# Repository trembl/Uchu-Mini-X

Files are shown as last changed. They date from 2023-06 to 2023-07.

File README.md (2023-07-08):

# 宇宙 Uchi Mini X4000

The 宇宙 (うちゅう, uchū) "Kosmos" Mini X4000 is a re-imagination of a popular Kosmos Electronics construction kits ("[Experimentierkasten](https://de.wikipedia.org/wiki/Experimentierkasten)") from th 1980ies.

I still have the instruction books for the X1000-X2000 and X3000-X4000 sets, but I only every got the X2000 and the X2500 Extenstion Set, I could make all the experiments up to the X3000, but not the X4000.

With this re-making of the complete set, I'll finally be able to make **all** the experiments!

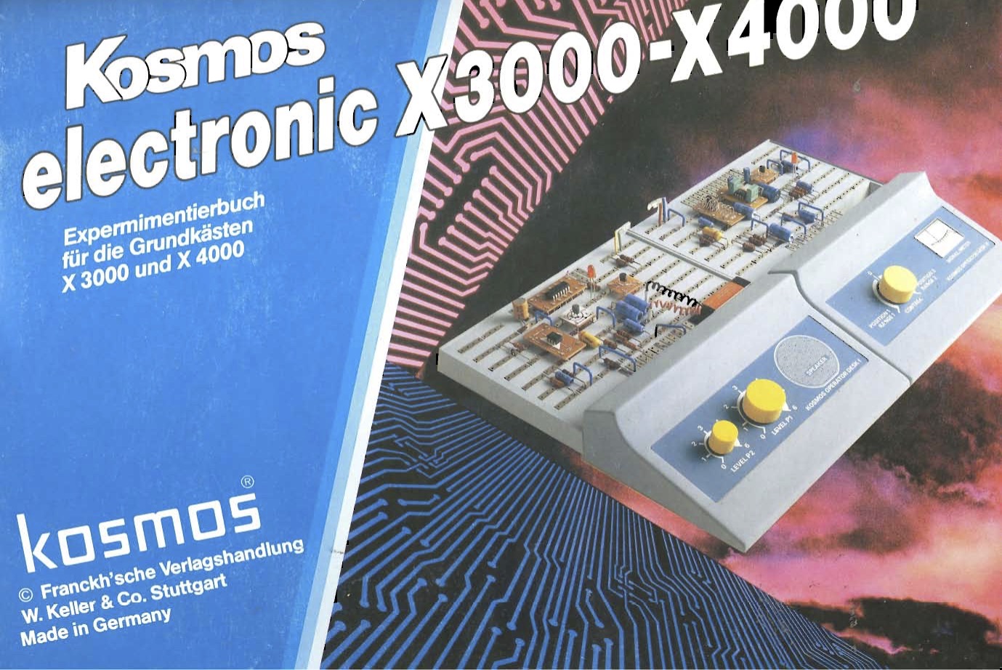
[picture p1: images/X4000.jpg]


The Kosmos X-Series was followed by the XN-Series, which introduces a different chassis and some addtional parts (Variable Capacitor, 555 Timer)

## Todo
- [X] Identify the parts and create a complete [BoM (Bill of Materials)](BoM.md)
- [X] Find where to source the parts - and how much they cost
- [X] PCB Design the Main Board
- [X] 3D Model the Main Board Carrier
- [ ] PCB Design the small carrier boards for IC, AMPs, etc
- [ ] Mill the Boards
- [ ] 3D Model the Console ("Schaltpult") & Enclosures
- [ ] 3D Print the Console & Enclosures

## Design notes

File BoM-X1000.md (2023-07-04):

# Bill of Materials X1000 (Box I)

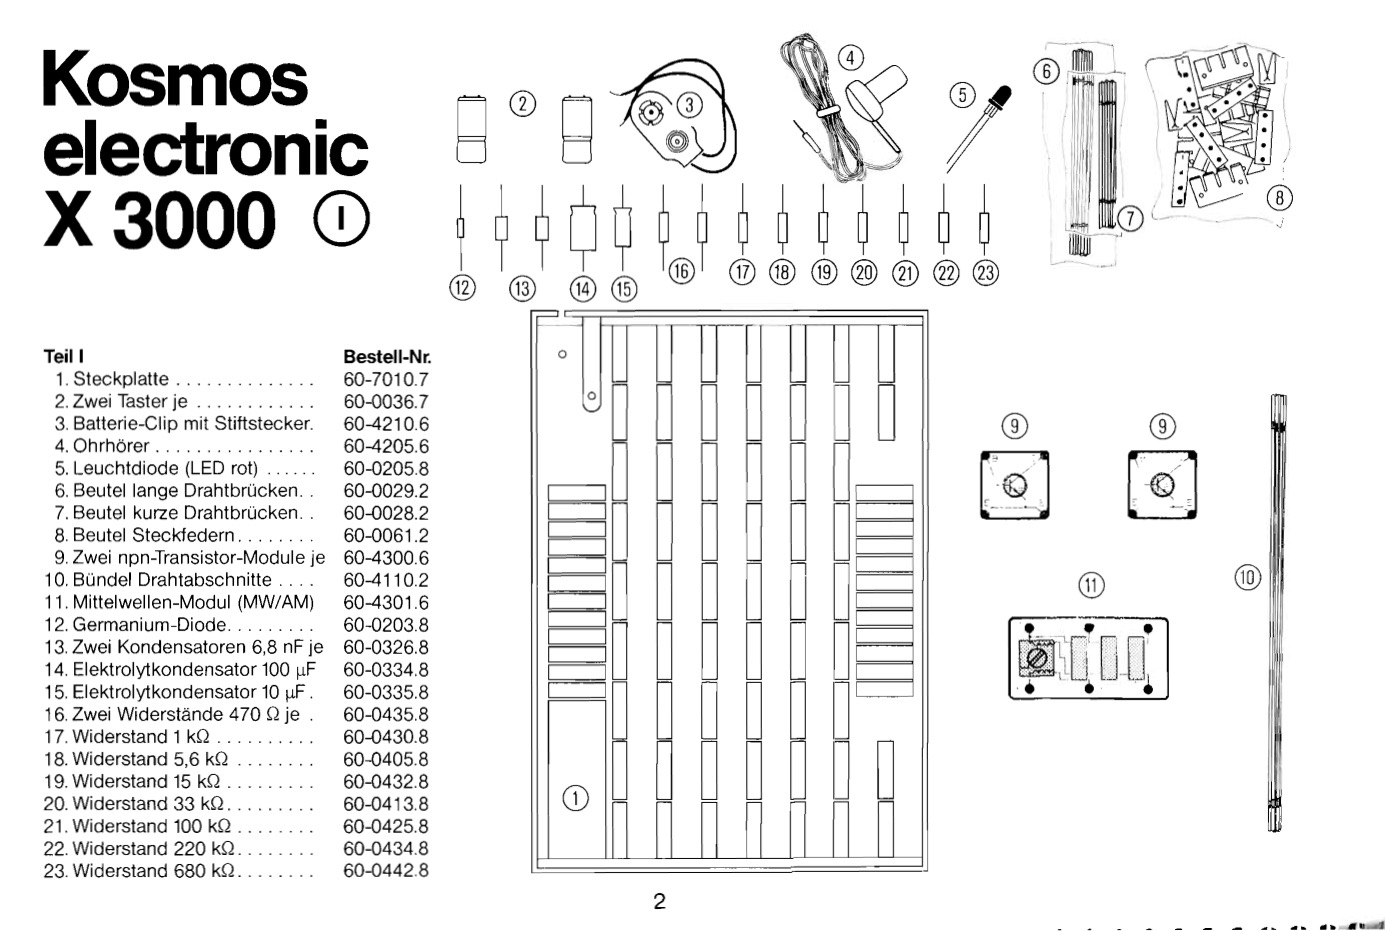
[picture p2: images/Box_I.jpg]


| Nr  | Description | Alternative | Package | Unit Price |  Bulk Price |
| --- | --- | --- | --- | --- | --- |
| 1.  | Main Board | TODO: 3D Design | | | |
| 2.  | Switch (x2) | [↓](#switch-module) | | | |
| 3.  | ✅ 9V Battery Clip | [9V Battery Clip](https://akizukidenshi.com/catalog/g/gP-00452/) 🅰️[^1] 1F06 | | ¥20 | |
| 4.  | Earpiece, 8Ω | TODO: Find with Crystal Radio Set | | | |
| 5.  | ✅ Red LED, 5mm | [Red LED, 5mm](https://akizukidenshi.com/catalog/g/gI-06245/) 🅰️[^1] 1F25/2 | Through-Hole | ¥12 | ¥120 for 10 |
| 6.  | ✅ Long Wires | [Wire Set](https://akizukidenshi.com/catalog/g/gP-05160/)| | ¥400 | |
| 7.  | Short Wires | See 6. | | | |
| 8.  | ✅ Pin Headers 1x4, 2.54mm, Black | [Pin Header 1x4](https://akizukidenshi.com/catalog/g/gC-10099/) 🅰️[^1] 1F12/下, C-10099| Through-Hole | ¥20 |  |
| 8.A  | Pin Headers 1x40, 2.54mm, Red, Yellow, Gray, Green | ✅ [Pin Header 1x40](https://akizukidenshi.com/catalog/g/gC-10299/), 🅰️[^1]1F12/下, C-10299 | Through-Hole | ¥100 | ¥10 for 1x4 |
| 8.B  | Pin Headers 1x40, 2.54mm, Black | ✅ [Pin Header 1x40](https://akizukidenshi.com/catalog/g/gC-10073/) 🅰️[^1] 1F12/下, C-10073| Through-Hole | ¥80 | ¥8 for 1x4 |
| 9.  | NPN Transitor Module (x2) | [↓](#npn-transistor-module) | | | |
| 10. | Very Long Wires | See 6. | | | |
| 11. | [MW/AM Module](https://www.rigert.com/ee-wiki/index.php?title=KOSMOS_Mittelwellen-Modul) | [↓](#mw-am-module) | | | |
| 12. | Diode (Germanium), AA112, AA118, 1N60, AA113 |⚠️ [1N60](https://akizukidenshi.com/catalog/g/gI-05507/) 🅰️[^1] 1F21/2, I-05507 | Through-Hole | ¥25 | 10 for ¥250 |
| 13.A | Capacitor 6.8nF (x2) | ⚠️ [6800pF50V X7R 5mm](https://akizukidenshi.com/catalog/g/gP-08137/) 🅰️[^1] 1F22/2, P-08137 | Through-Hole, Radial (x10) | ¥10 | ¥100 |
| 13.B | Capacitor 6.8nF (x2) | ⚠️ [XICON 23PS268 Styrofoam Capacitor 50V6800pF](https://www.sengoku.co.jp/mod/sgk_cart/detail.php?code=EEHD-4ET7#) 💎[^3] | Through-Hole, Axial | ¥111 | |
| 14.A | Capacitor 100µF, bi-polar, axial | ⚠️ [107BPA016M](https://www.digikey.jp/en/products/detail/cornell-dubilier-illinois-capacitor/107BPA016M/5410731) 🔑[^2] | Through-Hole, Axial | ¥198 | |
| 14.B | Capacitor 100µF, bi-polar | ⚠️ [100µF16V](https://akizukidenshi.com/catalog/g/gP-10271/) 🅰️[^1] 1F09/下, P-10271 | Through-Hole | ¥20 | |
| 14.C | Capacitor 100µF, bi-polar, axial | ⚠️ [100µF50V, UNICON GST1H101M](https://www.sengoku.co.jp/mod/sgk_cart/detail.php?code=EEHD-0GMP) 💎[^3] | Through-Hole | ¥105 | |
| 15.A | Capacitor 10µF, bi-polar, axial | ⚠️ [106BPA050M](https://www.digikey.jp/en/products/detail/cornell-dubilier-illinois-capacitor/106BPA050M/5410614) 🔑[^2] | Through-Hole, Axial | ¥150 | |
| 15.B | Capacitor 10µF, bi-polar | ⚠️ [10µF25V](https://akizukidenshi.com/catalog/g/gP-17877/) 🅰️[^1]1F09/下, P-17877 | Through-Hole | ¥20 | |
| 15.C | Capacitor 10µF, bi-polar, axial | ⚠️ [10µF50V, UNICON GST1H100M](https://www.sengoku.co.jp/mod/sgk_cart/detail.php?code=EEHD-0GMK) 💎[^3] | Through-Hole | ¥105 | |
| 16. | Resistor 470Ω (x2) | ✅ [1/2W 470Ω](https://akizukidenshi.com/catalog/g/gR-07814/) | Through-Hole, Axial (x100) | ¥1 | ¥100 |
| 17. | Resistor 1㏀ | ✅ [1/2W 1㏀](https://akizukidenshi.com/catalog/g/gR-07820/) | Through-Hole, Axial (x100) | ¥1.5 | ¥100 |
| 18. | Resistor 5.6㏀ | ✅ [1/4W 5.6㏀](https://akizukidenshi.com/catalog/g/gR-25562/) | Through-Hole, Axial (x100) | ¥1 | ¥100 |
| 19. | Resistor 15㏀ | ✅ [1/2W 15㏀](https://akizukidenshi.com/catalog/g/gR-07840/) | Through-Hole, Axial (x100) | ¥1 | ¥100 |
| 20. | Resistor 33㏀ | ✅ [1/2W 33㏀](https://akizukidenshi.com/catalog/g/gR-07812/) | Through-Hole, Axial (x100) | ¥1 | ¥100 |
| 21. | Resistor 100㏀ | ✅ [1/2W 100㏀](https://akizukidenshi.com/catalog/g/gR-07853/) | Through-Hole, Axial (x100) | ¥1 | ¥100 |
| 22. | Resistor 220㏀ | ✅ [1/2W 220㏀](https://akizukidenshi.com/catalog/g/gR-07858/) | Through-Hole, Axial (x100) | ¥1 | ¥100 |
| 23. | Resistor 680㏀ | ✅ [1/4W 680㏀](https://akizukidenshi.com/catalog/g/gR-25684/) | Through-Hole, Axial (x100) | ¥1 | ¥100 |

### General
| Nr  | Description | Alternative | Package | Unit Price |  Bulk Price |
| --- | --- | --- | --- | --- | --- |
| X  | Pin Headers 1x40 (x10)  | ⚠️ [Color Pin Headers](https://akizukidenshi.com/catalog/g/gC-06641/) 🅰️[^1]1F12/下, C-06641 | | ¥550 | ¥1.375 for 1 |
| X  | L-Pin Sockets 1x6 | ✅ [L-Pin Sockets](https://akizukidenshi.com/catalog/g/gC-03795/) 🅰️[^1]1F12/下, C-03795 | | ¥20 | |

### Switch Module
| Nr  | Description | Alternative | Package | Unit Price |  Bulk Price |
| --- | --- | --- | --- | --- | --- |
| 2.1  | SMD Switch (x2) | SMD Switch | | | |
| 2.2  | Module PCB | TODO: Design & Mill PCB Design | | | |

### NPN Transistor Module
| Nr  | Description | Alternative | Package | Unit Price |  Bulk Price |
| --- | --- | --- | --- | --- | --- |
| 9.1A  | NPN Transitor Module, BC583C, BC238C, BC548C BJT 100mA 30V NPN | ⚠️ [BC848BLT1G](https://www.digikey.jp/en/products/detail/onsemi/BC848BLT1G/918348) 🔑[^2] | SOT23-3 | ¥21 | ¥42 |
| 9.1B  | NPN Transitor Module 100mA 60V | ⚠️ [2PD601AR 50V100mA](https://akizukidenshi.com/catalog/g/gI-02231/) 🅰️[^1]NA, Online Only | SOT23 | 0.625¥ | 80 for ¥50 |
| 9.1C  | NPN Transitor Module 100mA 60V | ⚠️ [2SC3324-GR 120V100mA](https://akizukidenshi.com/catalog/g/gI-09371/) 🅰️[^1]1F23/4, I-09371 | SC-59 | 25¥ | 5 for ¥150 |
| 9.2  | Module PCB | TODO: Design & Mill PCB Design | | | |

### MW/AM Module
| Nr  | Description | Alternative | Package | Unit Price |  Bulk Price |
| --- | --- | --- | --- | --- | --- |
| 11.1 | Toko RCL XYRS 18194 N5 86152 | ⚠️ [Murata](https://www.digikey.jp/en/products/detail/murata-electronics/A1313B-0029GGH-P3/13244738) | 6-SMD | ¥226 |  |
| 11.2  | Capacitor 15pF | ⚠️ [15pF50V](https://akizukidenshi.com/catalog/g/gP-13312/) | 1608 | 2.5¥ | 40 for 100¥ |
| 11.2A  | Capacitor 15pF | ⚠️ [15pF250V](https://www.sengoku.co.jp/mod/sgk_cart/detail.php?code=EEHD-5S3X#) | 3216 | 10¥ | 50 for 500¥ |
| 11.3  | Capacitor 47pF | ⚠️ [47pF50V](https://akizukidenshi.com/catalog/g/gP-17481/)| 1608 | 2.5¥ | 40 for 100¥ |
| 11.3A  | Capacitor 47pF | ⚠️ [47pF250V](https://www.sengoku.co.jp/mod/sgk_cart/detail.php?code=EEHD-5PLJ) | 3216 | 10.5¥ | 50 for 525¥ |
| 11.4  | Capacitor 100pF | ⚠️ [100pF50V](https://akizukidenshi.com/catalog/g/gP-16524/) | Through-Hole | 6¥ | 10 for 60¥ |
| 11.4A  | Capacitor 100pF | ⚠️ [100pF50V](https://www.sengoku.co.jp/mod/sgk_cart/detail.php?code=EEHD-58F3) | 3216 | 35.8¥ | 5 for 179¥ |

Notes:
- Find 3216 SMDs instead of 1608
- https://www.eevblog.com/forum/projects/can-someone-identify-this-toko-rcl-component/
- https://www.boehri.de/elektronik/AM_Testsender_Kosmos_electronic_X1000.pdf
- https://www.murata.com/en-global/products/inductor/variable

[^1]: Akizuki Denshi
[^2]: Digikey
[^3]: Sengoku

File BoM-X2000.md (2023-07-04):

# Bill of Materials X2000 (Box II)

# ✅

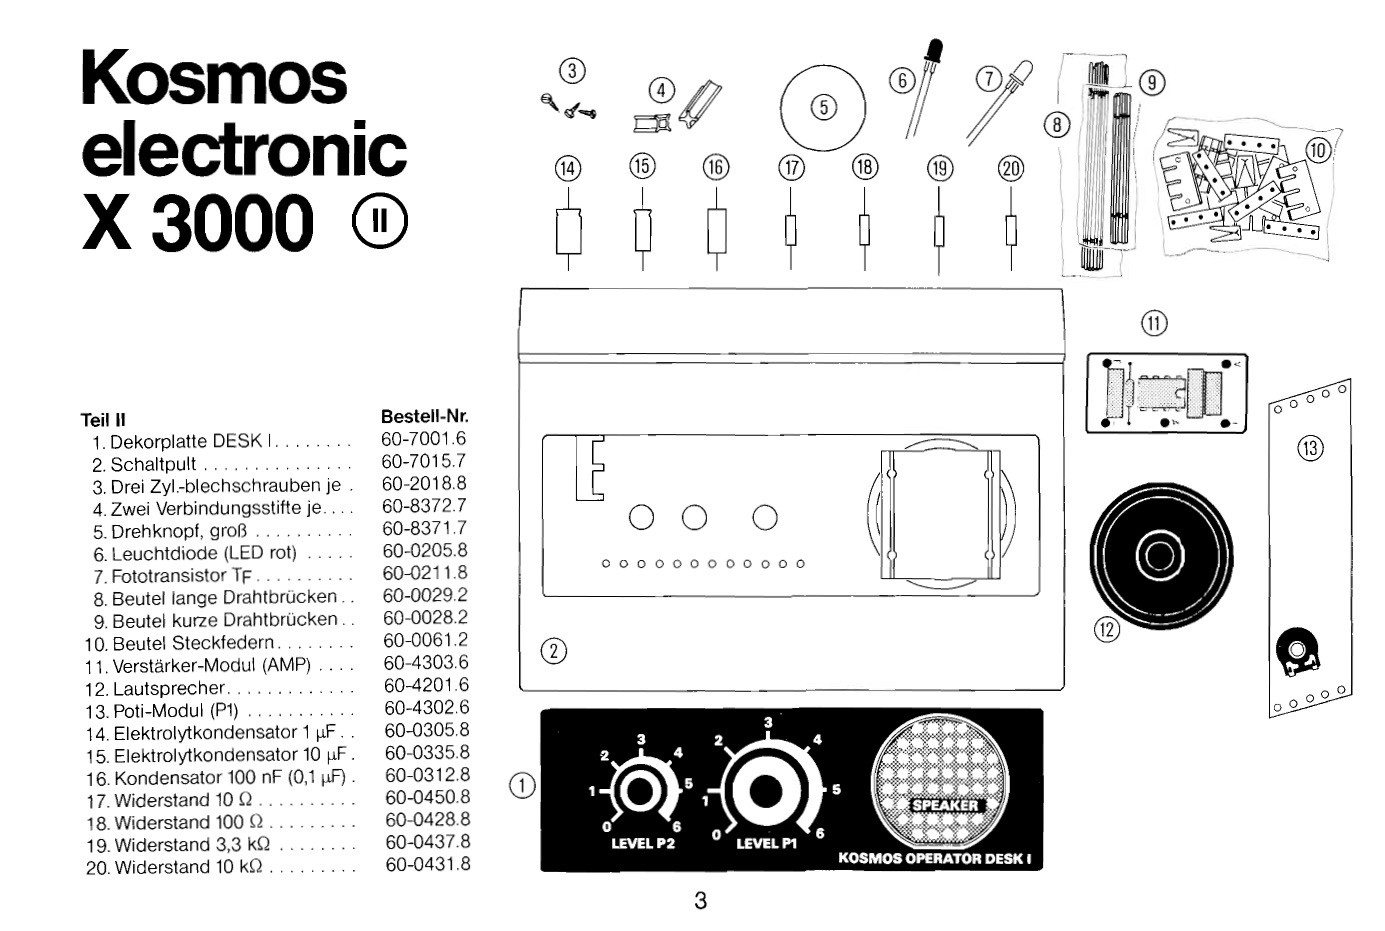
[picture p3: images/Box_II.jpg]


| Nr  | Description | Alternative | Package | Unit Price |  Bulk Price |
| --- | --- | --- | --- | --- | --- |
| 1.  | Decoration Plate | TODO: 2D Design & Lasercut | | | |
| 2.  | Console | TODO: 3D Design | | | |
| 3.  | ⚠️ Screws | | | | |
| 4.  | Connecting Rods | TODO: 3D Design | | | |
| 5.  | Knob, Large | [Black, 15mm](https://akizukidenshi.com/catalog/g/gP-00253/), [Grey, Blue](https://akizukidenshi.com/catalog/g/gP-06091/)[^1] | | | |
| 6.A  | ✅ Red LED, 5mm | [RED LED, 5mm](https://akizukidenshi.com/catalog/g/gI-06245/)[^1] 🅰️[^1] 1F25/2, I-06245 | Through-Hole | ¥12 | ¥120 for 10 |
| 6.B  | ⚠️ Red LED, 3mm | [RED LED, 3mm](https://akizukidenshi.com/catalog/g/gI-11577/)[^1], 🅰️[^1] 1F25/2, I-11577 | Through-Hole | ¥10 |  |
| 7.A  | ⚠️ Photo Transistor, 560nm | [Photo Transistor](https://akizukidenshi.com/catalog/g/gI-02325/)[^1] 🅰️[^1] 1F18/5, I-02325 | Through-Hole | ¥50 | ¥100 for 2 |
| 7.B  | ⚠️ Photo Transistor, 3mm, 440 to 800 nm | [Photo Transistor](https://www.sengoku.co.jp/mod/sgk_cart/detail.php?code=EEHD-4HXG)[^3] 💎[^3] | Through-Hole | ¥84 |  |
| 8.  | ✅ Long Wires | See Box I.6 | | | |
| 9.  | ✅ Short Wires | See Box I.6 | | | |
| 10. | ✅ Pin Headers 1x4, 2.54mm x 9 x 7 | See Box I.8  | Through-Hole | ¥20 |  |
| 11. | [AMP](https://www.rigert.com/ee-wiki/index.php/KOSMOS_Verstärker-Modul) Amplication Module | [↓](#amp-module) | | | |
| 12.A | ✅ Speaker, ⌀50mm[^4], 8Ω | [⌀50mm, 8Ω](https://akizukidenshi.com/catalog/g/gP-09013/) 🅰️[^1] 2F/73, P-09013| | ¥180 | |
| 12.B | ⚠️ Speaker, ⌀28mm, 8Ω | [⌀28mm, 8Ω](https://akizukidenshi.com/catalog/g/gP-12587/) 🅰️[^1] 1F/05, P-12587| | ¥190 | |
| 13.  | ⚠️ Potentiometer Module (P1)[^5]  10KΩ lin. (B) | [10ＫΩＢ](https://akizukidenshi.com/catalog/g/gP-15813/) 🅰️[^1] 1F33, P-15813 | | ¥60 | |
| 14.  | ⚠️ Capacitor 1µF, bi-polar, axial | [GST1H1R0M, 1µF50V](https://www.sengoku.co.jp/mod/sgk_cart/detail.php?code=EEHD-0GMG) 💎[^3] | Through-Hole, Axial |¥105 | | 
| 15.  | ⚠️ Capacitor 10µF, bi-polar, axial | see Box I.14  | | | | 
| 16.  | ⚠️ Capacitor 100nF, 0.1µF | [FYU6104Z6 50V 0.1μF](https://www.sengoku.co.jp/mod/sgk_cart/detail.php?code=EEHD-06D3) 💎[^3] | Through-Hole | | | 
| 17. | ✅ Resistor 10Ω | [1/4W 10Ω](https://akizukidenshi.com/catalog/g/gR-07805/)  | Through-Hole, Axial (x100) | ¥1 | ¥100 for 100|
| 18. | ✅ Resistor 100Ω | [1/4W 100Ω](https://akizukidenshi.com/catalog/g/gR-07805/)  | Through-Hole, Axial (x100) | ¥1 | ¥100 for 100|
| 19. | ✅ Resistor 3.3㏀ | [1/4W 3.3㏀](https://akizukidenshi.com/catalog/g/gR-25103/)  | Through-Hole, Axial (x100) | ¥1 | ¥100 for 100 |
| 20. | ✅ Resistor 10㏀ | [1/4W 10㏀](https://akizukidenshi.com/catalog/g/gR-25223/)  | Through-Hole, Axial (x100) | ¥1 | ¥100 for 100 |

### AMP Module

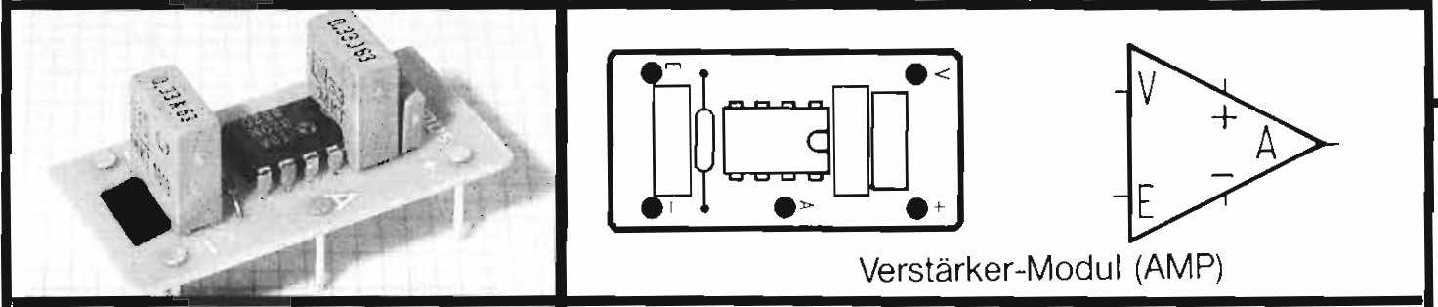
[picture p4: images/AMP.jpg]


| Nr  | Description | Alternative | Package | Unit Price |  Bulk Price |
| --- | --- | --- | --- | --- | --- |
| 11.1 | ⚠️ Film Capacitor 330pF, 100V, WIMA | [330pF 63V WIMA](https://www.sengoku.co.jp/mod/sgk_cart/detail.php?code=EEHD-4ETP) 💎[^3] | Through Hole | ¥69|  |
| 11.2 | ⚠️ 2x Film Capacitor 330nF = 0.33µF, 63V, WIMA MKS-4 | [MKS2 63V 0.33μF](https://www.sengoku.co.jp/mod/sgk_cart/detail.php?code=EEHD-0GN5) 💎[^3] | Through Hole | ¥105 | |
| 11.3 | ✅ Resistor 10Ω | See 17| Through-Hole | | |
| 11.4 | ✅ IC [TBA820](https://www.st.com/resource/en/datasheet/cd00000118.pdf) | [TBA820M](https://akizukidenshi.com/catalog/g/gI-17301/) 🅰️[^1] | DIP-8 | ¥30 |  |
| 11.5 | Module PCB, Through Hole Design | PCB Design & Mill | | | |

[^1]: Akizuki Denshi
[^2]: Digikey
[^3]: Sengoku
[^4]: ⌀50mm is too large for Mini Console
[^5]: [E200_Bauteile](https://www.rigert.com/ee-wiki/index.php?title=KOSMOS_E200_Bauteile)

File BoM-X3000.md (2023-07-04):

# Bill of Materials X3000 (Box III)

| Nr  | Description | Alternative | Package | Unit Price |  Bulk Price |
| --- | --- | --- | --- | --- | --- |
| 1.  | Main Board | | | | |
| 2.  | ⚠️ Screws (x3) | | | | |
| 3.  | Switch | | | | |
| 4.  | Connecting Rods | | | | |
| 5.  | Knob, Small | | | | |
| 6.  | ✅ 9V Battery Clip | see Box I.3 | | | |
| 7.A | ⚠️ IR LED, 5mm, blue tinted | [5mm IR LED](https://akizukidenshi.com/catalog/g/gI-13204/) 🅰️[^1] 1F26/4, I-13204| Through-Hole | ¥20 | |
| 7.B | ⚠️ IR LED, 3mm, blue tinted | [3mm IR LED](https://akizukidenshi.com/catalog/g/gI-04313/) 🅰️[^1] 1F26/4, I-04313| Through-Hole | ¥20 | ¥200 for 10 |
| 8.  | Long Wires | | | | |
| 9.  | Short Wires | | | | |
| 10.  | ✅ Pin Headers 1x4, 2.54mm x 9 x 7 | see Box I.8 |  |  |  |
| 11.  | ⚠️ Potentiometer Module (P2) 100KΩ pos. log. (A)[^5] | [100ＫΩA](https://akizukidenshi.com/catalog/g/gP-16477/) 🅰️[^1] 1F33, P-16477 | | ¥60 | |
| 12.  | ⚠️ [UKW/FM Module](https://www.rigert.com/ee-wiki/index.php/KOSMOS_UKW-Modul) | [↓](#ukw-fm-modlue) | | | | 
| 13. | 2x Diode (Silicium Diode) | BA147, 1N4148 | [1N4148 100V200mA](https://akizukidenshi.com/catalog/g/gI-00941/) 🅰️[^1] 1F21/2, I-00941| Through-Hole | ¥15 |
| 14.  | ⚠️ Elko 10µF | see Box I.15 | | | | 
| 15.  | ⚠️ Elko 100µF, x2 | see Box I.14 | | | | 
| 16.  | ⚠️ Elko 470µF |  [50V470μF](https://www.sengoku.co.jp/mod/sgk_cart/detail.php?code=EEHD-0GMT) 💎[^3]  | | | | 
| 17.  | ⚠️ Capacitor 100nF | see Box II.16 | | | | 
| 18. | ✅ Resistor 150Ω | [1/4W 150Ω](https://akizukidenshi.com/catalog/g/gR-07805/)  | Through-Hole, Axial (x100) | ¥1 | ¥100 for 100|
| 19. | ✅ Resistor 1.5㏀ | [1/4W 1.5㏀ ](https://akizukidenshi.com/catalog/g/gR-25152/) | Through-Hole, Axial (x100) | ¥1 | ¥100 for 100 |
| 20. | ✅ Resistor 2.7㏀ | [1/4W 2.7㏀](https://akizukidenshi.com/catalog/g/gR-25272/) | Through-Hole, Axial (x100) | ¥1 | ¥100 for 100 |
| 21. | ✅ Resistor 10㏀ | [1/4W 10㏀](https://akizukidenshi.com/catalog/g/gR-25103/)  | Through-Hole, Axial (x100) | ¥1 | ¥100 for 100 |
| 22. | ✅ Resistor 22㏀ | [1/4W 22㏀](https://akizukidenshi.com/catalog/g/gR-25223/)  | Through-Hole, Axial (x100) | ¥1 | ¥100 for 100 |

### UKW/FM Module
| Nr  | Description | Alternative | Package | Unit Price |  Bulk Price |
| --- | --- | --- | --- | --- | --- |
| 12.1  | ⚠️ BF256A, JFET N-Kanal | [J-FET MMBFJ310](https://akizukidenshi.com/catalog/g/gI-10680/) 🅰️[^1] 1F23/3, I-10680| SOT-23| ¥20 | ¥100 for 5 |
| 12.2  | ⚠️ [BB505B](https://www.box73.de/file_dl/bauelemente/BB505B.pdf) Varicap Diode, Varactor, V<sub>RM</sub>=30V, I<sub>F</sub>=20mA | [Sony 1T32](https://akizukidenshi.com/catalog/g/gI-16087/) 🅰️[^1] I-16087, Ask | SMD | ¥60 | |
| 12.3 | ⚠️ Capacitor 56pF | [GRM21A5C2E560JW01D](https://www.sengoku.co.jp/mod/sgk_cart/detail.php?code=EEHD-5S4A) 💎[^3] | SMD 2012  | ¥32 | |
| 12.4 | ⚠️ Capacitor 4.7nF, (=4700pF) | [GRM2195C1H472JA01D](https://www.sengoku.co.jp/mod/sgk_cart/detail.php?code=EEHD-5PLP) 💎[^3] | SMD 2012 | ¥32 | | 
| 12.5 | Module PCB | TODO: Design & Mill | | | |

[^1]: Akizuki Denshi
[^2]: Digikey
[^3]: Sengoku
[^5]: [E200_Bauteile](https://www.rigert.com/ee-wiki/index.php?title=KOSMOS_E200_Bauteile)

Notes:
- https://www.rigert.com/ee-wiki/index.php/KOSMOS_UKW-Modul

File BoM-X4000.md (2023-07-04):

# Bill of Materials X4000 (Box IV)

| Nr  | Description | Alternative | Package | Unit Price |  Bulk Price |
| --- | --- | --- | --- | --- | --- |
| 1.  | Decoraton Plate II | TODO: 2D Design | | | |
| 2.  | Console | TODO: 3D Design | | | |
| 3.  | 3 Screws | | | | |
| 4.  | 2 Connecting Rods | | | | |
| 5.  | Switch | | | | |
| 6.  | Knob, Large | [Wire Set](https://akizukidenshi.com/catalog/g/gP-05160/)| | ¥400 | |
| 7.  | PNP Transitor Module | [↓](#pnp-transistor-module) | | | |
| 8.  | Long Jumper Wires | | | | |
| 9.  | Short Jumper Wires | | | | |
| 10.  | Pin Headers 1x4, 2.54mm  | see Box I | | |  |
| 11.  | Quad NAND Gate Module | [↓](#quad-nand-gate-module) | | |  |
| 12.  | IC [OP AMP Module](https://www.rigert.com/ee-wiki/index.php?title=KOSMOS_Operationsverstärker-Modul), [741](https://www.rigert.com/ee-wiki/index.php?title=741) | [↓](#op-amp-module) | | | | |
| 13.  | N/A | | | | |
| 14  | ⚠️ Ampere Meter, Ammeter 100µA, 1.2㏀ | [100µA, 1.8㏀, 50x50mm](https://akizukidenshi.com/catalog/g/gM-00139/) 🅰️[^1] 1F25/3 | | ¥1350 |  |
| 15. | ✅ Resistor 1.2Ω | [1/4W 1.2Ω](https://akizukidenshi.com/catalog/g/gR-25122/)  | Through-Hole, Axial (x100) | ¥1 | ¥100 for 100 |
| 16. | ✅ Resistor 12Ω | [1/4W 12Ω](https://akizukidenshi.com/catalog/g/gR-14271/) | Through-Hole, Axial (x100) | ¥1 | ¥100 for 100 |
| 17. | ✅ Resistor 10㏀ | [1/4W 10㏀](https://akizukidenshi.com/catalog/g/gR-25103/)  | Through-Hole, Axial (x100) | ¥1 | ¥100 for 100 |
| 18. | ✅ Resistor 39㏀ | [1/4W 39㏀](https://akizukidenshi.com/catalog/g/gR-25393/)  | Through-Hole, Axial (x100) | ¥1.3 | ¥130 for 100|
| 19. | ✅ Resistor 1MΩ | [1/4W 1MΩ](https://akizukidenshi.com/catalog/g/gR-25105/) | Through-Hole, Axial (x100) | ¥1 | ¥100 for 100 |
| 20. | ✅ Resistor 1.5MΩ | [1/4W 1.5MΩ](https://akizukidenshi.com/catalog/g/gR-14291/) | Through-Hole, Axial (x100) | ¥1 | ¥100 for 100 |

### Quad NAND Gate Module
| Nr  | Description | Alternative | Package | Unit Price |  Bulk Price |
| --- | --- | --- | --- | --- | --- |
| 11.1 | ⚠️ IC Quad NAND Gate SN7403N, TL7403N | [TC4011BP](https://akizukidenshi.com/catalog/g/gI-13729/) 3~18V 🅰️[^1] 1F13/下, I-13729| DIP14 |¥50 | |
| 11.2  | Module PCB | TODO: Design & Mill | | | | |

More about 7403 & 4011 as alternative:
- https://www.build-electronic-circuits.com/7400-series-integrated-circuits/74hc03-74ls03/
- https://www.experimentierkasten-board.de/viewtopic.php?p=4002

### PNP Transistor Module
| Nr  | Description | Alternative | Package | Unit Price |  Bulk Price |
| --- | --- | --- | --- | --- | --- |
| 7.1 | ⚠️ Transistor PNP, BC513B, BC308B, BC558B, BJT 100mA 30V PNP | [2PB709AR 45V100mA](https://akizukidenshi.com/catalog/g/gI-02232/) 🅰️[^1] Ask, I-02232| SMD SC-59 | ¥0.625 | ¥80 for 50
| 7.2  | Module PCB | TODO: Design & Mill | | | | |

### OP AMP Module
| Nr  | Description | Alternative | Package | Unit Price |  Bulk Price |
| --- | --- | --- | --- | --- | --- |
| 12.1  | ✅ [741](https://www.rigert.com/ee-wiki/index.php?title=741), LM741 | [NJM741D](https://akizukidenshi.com/catalog/g/gI-12128/) 🅰️[^1] 1F12/上, I-12128 | DIP8 |  ¥40 | |
| 12.2  | Module PCB | TODO: Design & Mill | | | | |

[^1]: Akizuki Denshi
[^2]: Digikey
[^3]: Sengoku

Notes:
- https://www.coda-effects.com/2018/08/the-different-types-of-diodes.html
- https://www.experimentierkasten-board.de/viewtopic.php?p=940
- https://www.eevblog.com/forum/beginners/how-to-know-if-my-logic-ic-is-fried/
- https://www.experimentierkasten-board.de/viewtopic.php?p=2389
- https://www.electronics-tutorials.ws
- https://www.eevblog.com/forum/projects/can-someone-identify-this-toko-rcl-component/
- https://www.elektronik-labor.de/Lernpakete/Radiobasteln.pdf
- https://forum.electronicwerkstatt.de/phpBB/Elektrische_Probleme/verstaerkermodul_kosmos-t10628f6_bs0.html
- https://www.experimentierkasten-board.de/viewtopic.php?p=3396

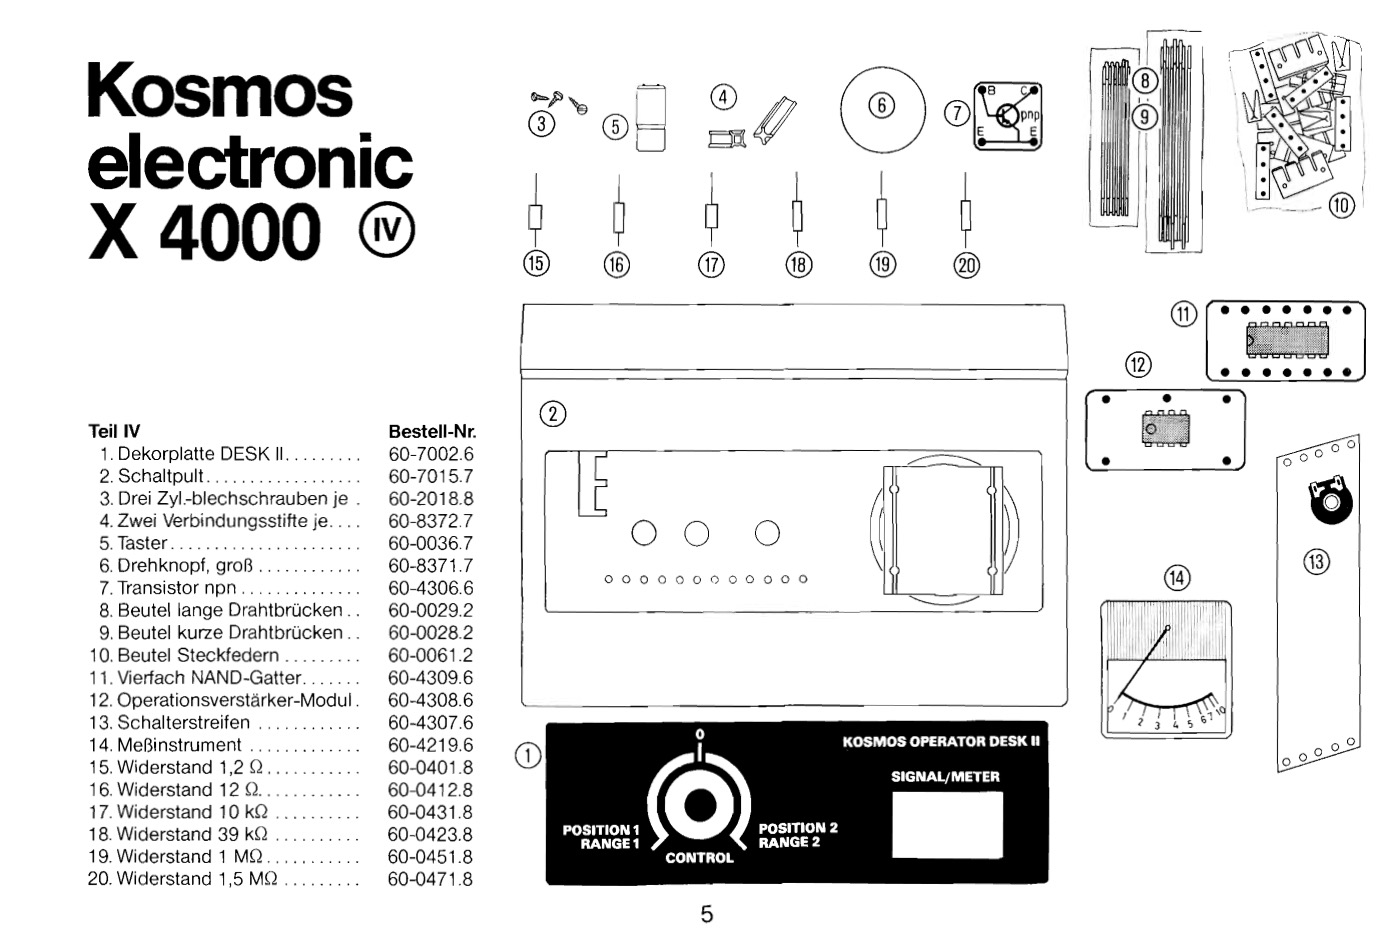
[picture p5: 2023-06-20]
images/Box_IV.jpg

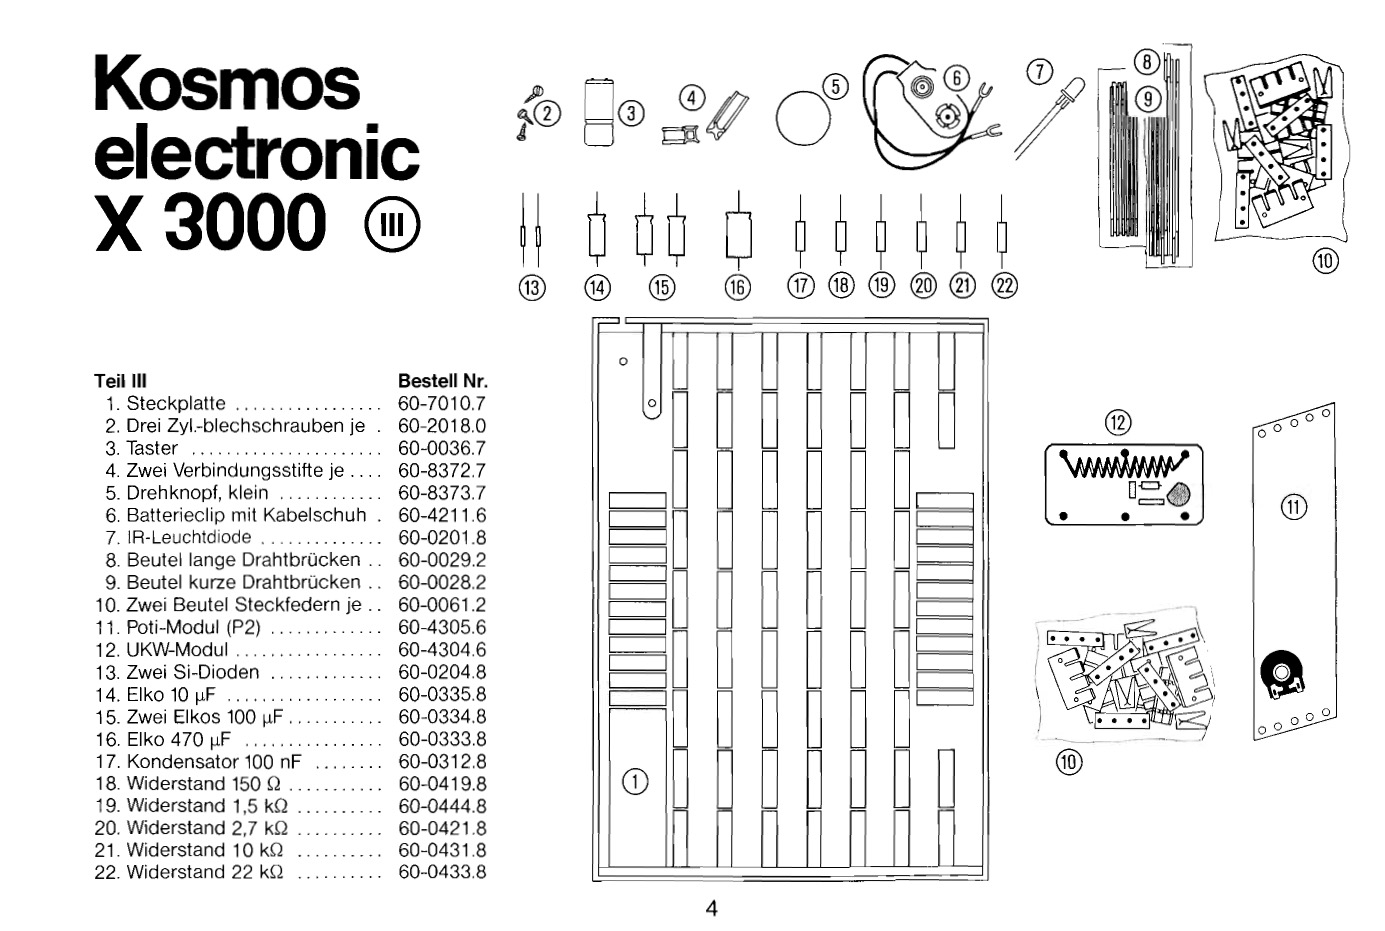
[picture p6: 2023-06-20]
images/Box_III.jpg

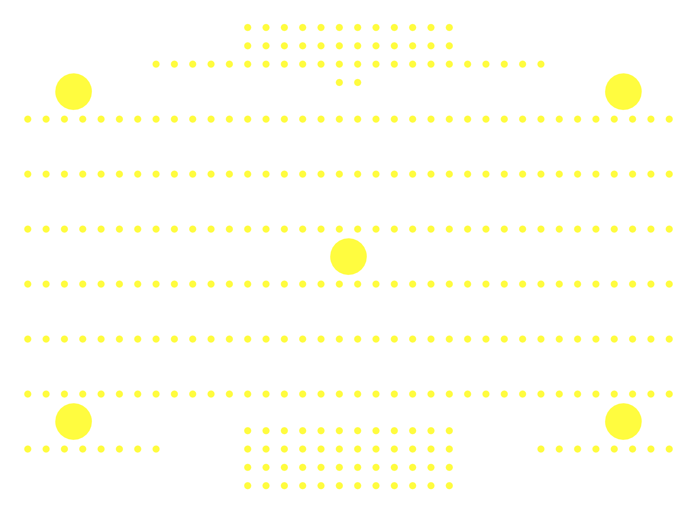
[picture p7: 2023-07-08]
Board/SVG-PCB/With Case/uchu-holes.png

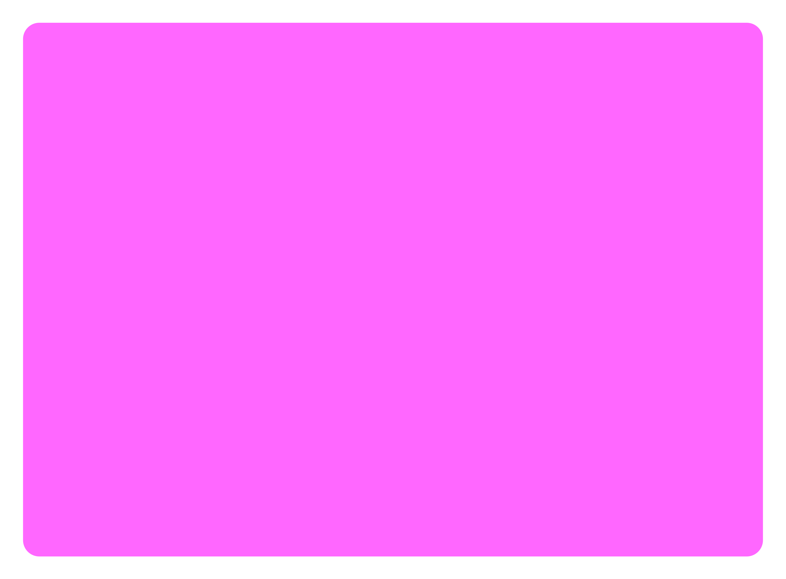
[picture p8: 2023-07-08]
Board/SVG-PCB/With Case/uchu-interior.png

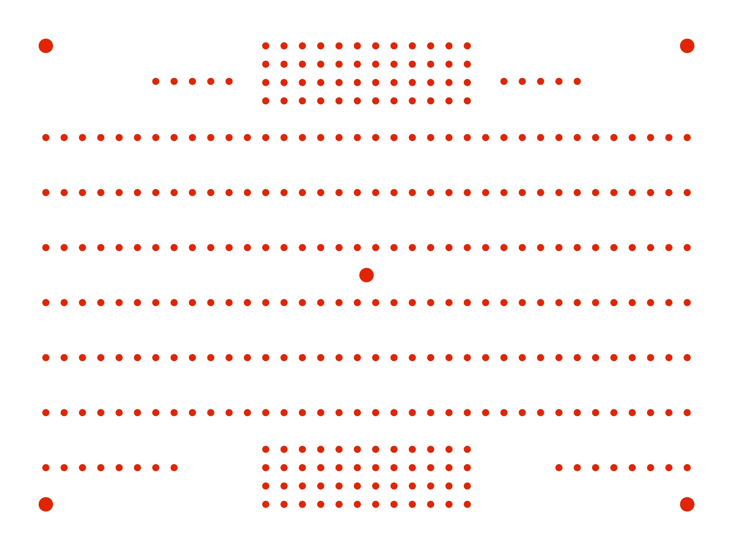
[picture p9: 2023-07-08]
Board/SVG-PCB/No Case/uchu-no-case_holes.png

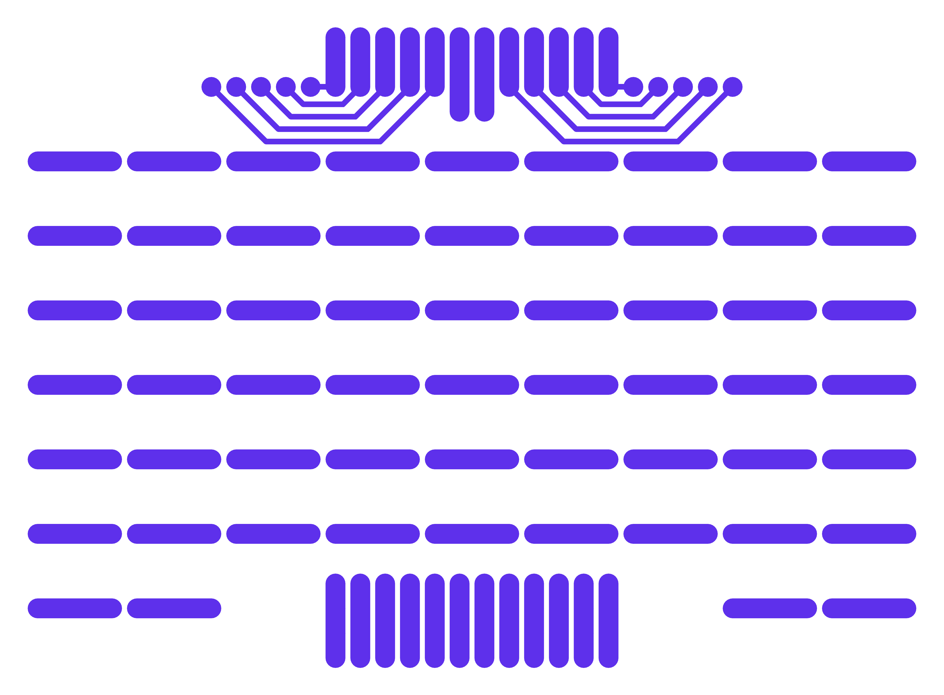
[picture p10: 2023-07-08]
Board/SVG-PCB/With Case/uchu-traces.png

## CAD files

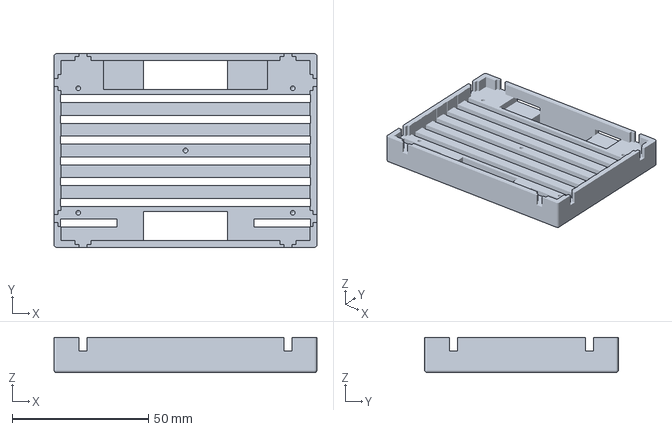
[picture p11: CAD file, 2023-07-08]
Case/OnShape/Uchu_Case_v2.3mf
96.5 x 71.1 x 13.0 mm

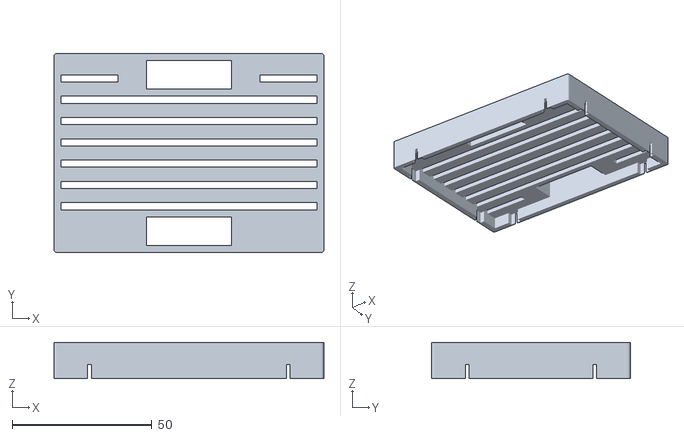
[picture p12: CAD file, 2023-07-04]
Case/OpenSCAD/Uchu-Case_v0.stl
96.5 x 71.1 x 13.0

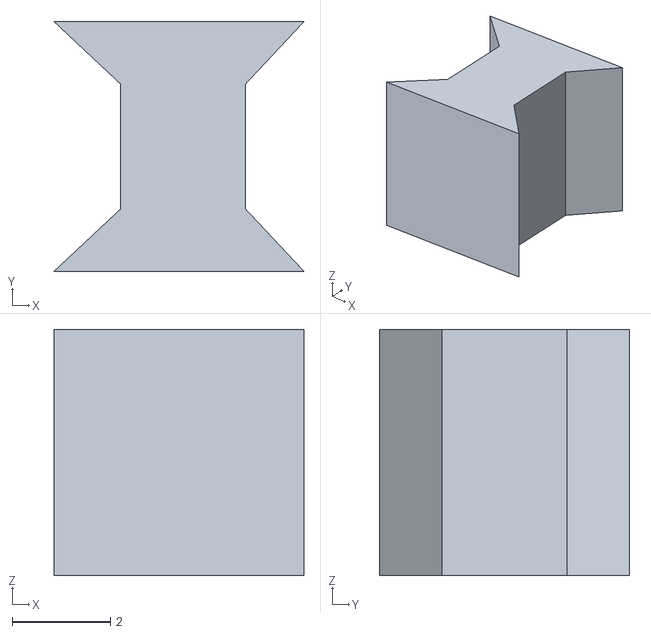
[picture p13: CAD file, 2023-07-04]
Case/OnShape/Uchu_Connector_v1.stl
5.08 x 5.07 x 5.00

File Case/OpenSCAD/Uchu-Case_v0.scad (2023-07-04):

echo(version=version());

include <roundedcube.scad>

$fn = 25;
// simple 2D -> 3D extrusion of a rectangle

// base


// OuterBox

unit = 2.54;

h = 13;             // pin header = 12mm + 1mm spacer
pin_h = 8;          // plastic encased part of pin header
case_radius = 1;

wall = unit * 2;

part_per_row = 9;
part_length = 4 * unit;
part_width = unit;
row_length = part_length * 9;

a = unit + row_length + unit;
b = part_length * 7;



    
difference() {
  color("Blue")
  
  // Main Case
  roundedcube([a, b, h], true, case_radius, "z");
  
  // Bottom Diff
  translate([0, 0, -pin_h]) { 
    cube([a-wall, b-wall, h], true);
  }
  
  // Long Rows x9
  for ( i = [0:1:2]) { // loop 
    y = unit + unit/2 + unit*3*i;
    translate([0, y, 0]) { 
      cube([row_length, unit, h+1], true);
    }
    translate([0, -y, 0]) { 
      cube([row_length, unit, h+1], true);
    }
  }
  
  // Top Short Rows, x2
  translate([-part_length*3.5, unit*10.5, 0]) { 
    cube([part_length*2, unit, h+1], true);
  }
  translate([part_length*3.5, unit*10.5, 0]) { 
    cube([part_length*2, unit, h+1], true);
  }

  // Vertical Connecting Pins
  dist = unit*11;
  translate([0, dist, 0]) { 
    cube([part_width*12, part_length, h+1], true);
  }
  translate([0, -dist, 0]) { 
    cube([part_width*12, part_length, h+1], true);
  }
  
  
  c(a/2, unit*9);
  c(a/2, -unit*9);
  
  mirror([1,0,0]) c(a/2, unit*9);
  
  mirror([1,0,0]) c(a/2, -unit*9);
  
  rotate([0,0,90]) c(b/2, b/2);
  
  rotate([0,0,90]) c(b/2, -b/2);
  
  rotate([0,0,90]) mirror([1,0,0]) c(b/2, b/2);
  
  rotate([0,0,90]) mirror([1,0,0]) c(b/2, -b/2);

}

 
 
  



module c(x, y) {
  translate([x, y, -pin_h]) {
    translate([-unit/2, 0, 0]) { 
      cube([unit, unit/2, h], true);
      translate([-unit/4, 0, 0]) { 
        cube([unit, unit*2, h], true);
      }
    }
  }
}





// Board Connectors

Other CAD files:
Case/OnShape/Uchu_Case_v2.stl

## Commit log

2023-07-04 Design Changes
    [Uchu-Case_v0.scad, Uchu-Case_v0.stl, Uchu_Case_v1.3mf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]
2023-07-08 New Board Designs
2023-07-08 Case Updates
    [Uchu_Case_v1.3mf, Uchu_Case_v1.stl, Uchu_Case_v2.3mf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]
